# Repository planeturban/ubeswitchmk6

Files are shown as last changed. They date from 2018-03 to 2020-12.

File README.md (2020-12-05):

# Main functions
* Atari DIN13 to VGA
* 3.5mm A/V connector with volume control.
* Automatic detection of resolution.

# v1.4 update
Added a AG-pad (AG after the guy who requested it) cut trace and connect the other pad to feed h-sync to PB2 instead of v-sync. Updates to firmware is needed.

Please be aware that the PCB is **unrouted** since different PCB houses has different tolerances and it **might** mess up the end product. 

# Manual
Plug device into your Atari.

Turn your Atari on.

Press .25-1.999[...] seconds: Switch mode.

Press +2 seconds: store current mode as default at cold boot.

# Assembly tips
For least amount of wobbliness:
1. Backside SMD stuff (TS5V330, ATtiny85 and 78l05). 
2. Flip board over, solder all SMD.
3. DIN13
4. Lastly solder volume pot and VGA. Flipping of board is optional if you're a good at soldering.

# BOM
Part|Value|Device|Package|Description|MF|MPN|OC_FARNELL|OC_NEWARK|PACKAGE|PROD_ID|SUPPLIER|
--|--|----|----|---|--|---|-|-|-|-|-|
ATARIOUT|DIN13T|DIN13T|DIN13|||||||||
IC2|78L05F|78L05F|SOT89|POSITOIV-VOLTAGE REGULATORS||||||||
JP1||PINHD-1X2|1X02|PIN HEADER||||||||
S2||K2-1823SA||||||||||
TM1-3|100R|TRIMPOTTC33X|TC33X|SMT trimmer potentiometer part number TC33X||||||||
TS5V330||V330|SOIC16N|||||||||
U$1||PJ-320D||Audio jack - 3.5mm TRRS variety - two rings.||||||CONN-10676||
U$2|DB-1001N|DB-1001N|THUMB_POT|Multicomp||||||||
U1|ATTINY85-20SU|ATTINY85-20SU|SOIC127P798X216-8N|8-bit Microcontroller with In-System Programmable Flash||ATTINY85-20SU|1455164|58M3797|SOIC-8||Atmel|
X1||F15HDVS|HDF15V|SUB-D|||unknown|unknown||||

# Troubleshooting
 Symptom        | Solution|
| ------------- |:------|
|Constant switching|Check ATtiny soldering, probably rebooting. +5V and GND are possible offenders.|
|Dark picture.|Check soldering on multiplexer, pin 8 and 16 (GND and VCC).|
|Physical switch not working, software switching works.| Check soldering at ATtiny PB4 and soldering at the tactile switch itself.|
|Niether software or hardware switching works.| Check soldering ATtiny PB3 and multiplexer pin 1.|
|Niether software or hardware switching works, boots in low res.| Did you remember to program your ATtiny?|
|Software switch not working|Check soldering on ATtiny PB2 and V-sync on DIN|
|Hardware switch slow.|Did you set fuses ("Burn bootloader" in Arduino IDE) before programming ATtiny? Processor is probably running in 1MHz.|
|Won't hold saved state, switches to hires after cold boot.|Try upping bootWait, probably some timing issues at boot. A recap of PSU might be in place as well.|

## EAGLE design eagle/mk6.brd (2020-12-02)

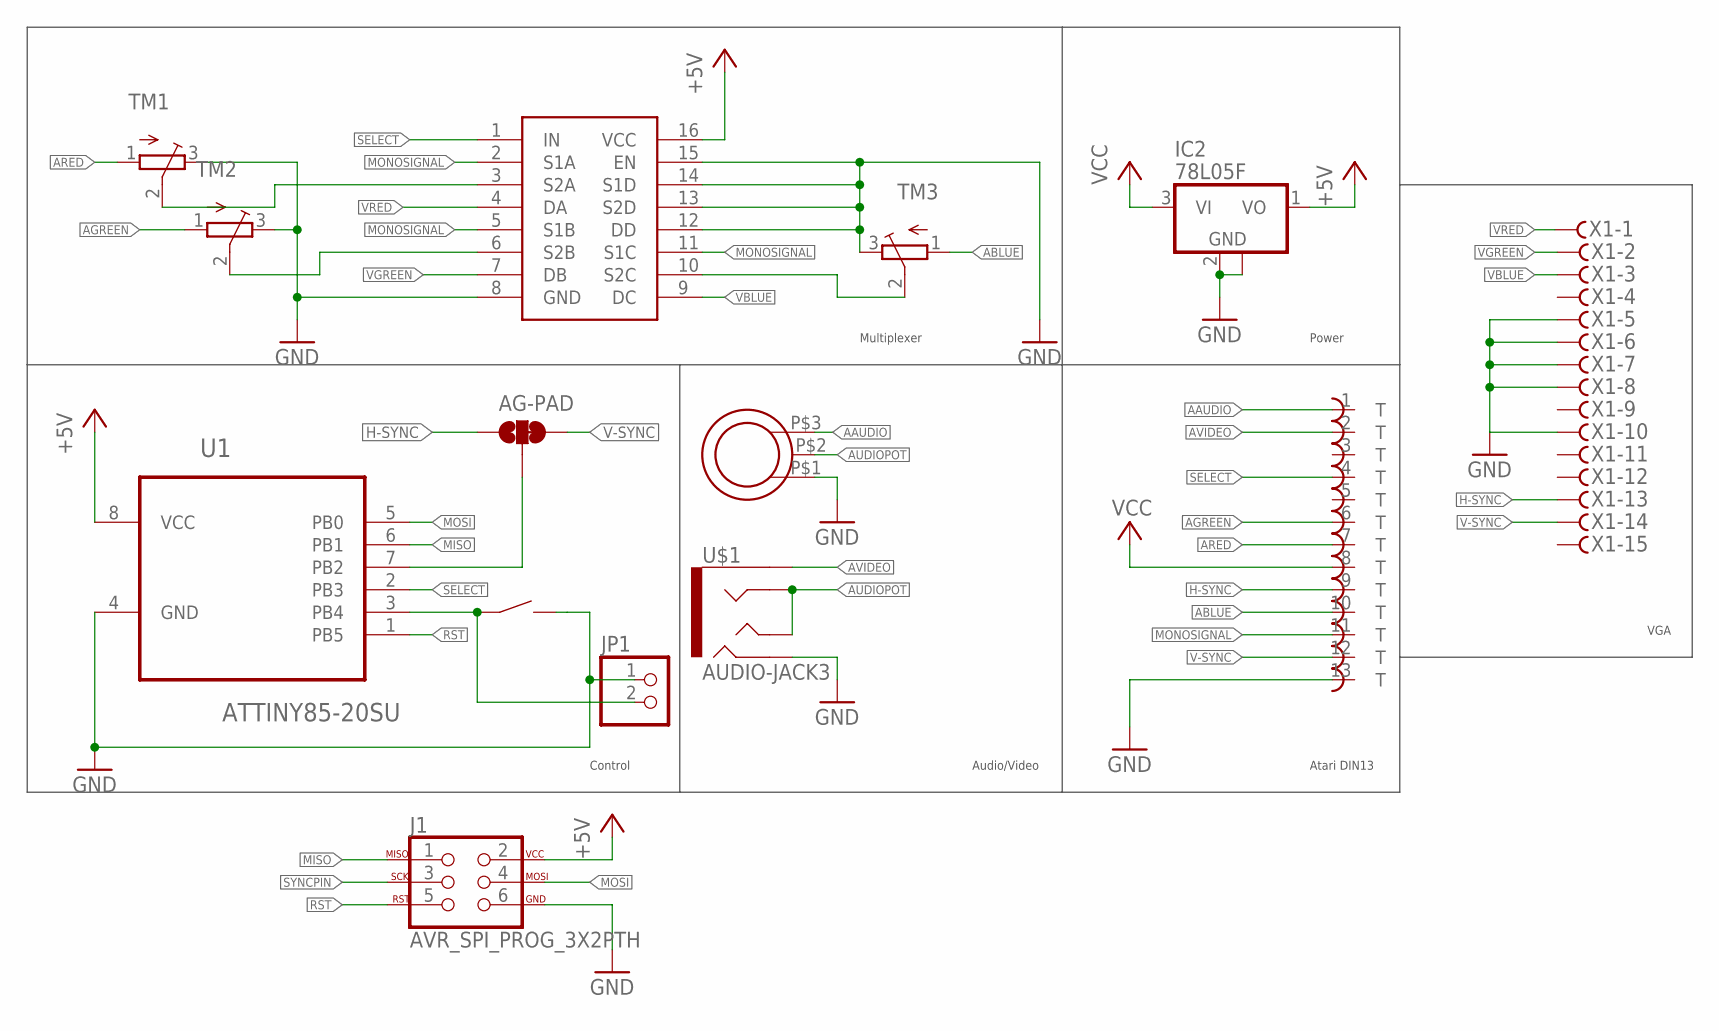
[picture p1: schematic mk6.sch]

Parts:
AG-PAD: JUMPER-SMT_3_1-NC_TRACE_SILK; SMT-JUMPER_3_1-NC_TRACE_SILK
ATARIOUT: DIN13T; ADADS
IC2: 78L05F; SOT89
J1: AVR_SPI_PROG_3X2PTH; 2X3
JP1: PINHD-1X2; 1X02
S2: K2-1823SA
TM1, TM2, TM3: TRIMPOTTC33X; TC33X
TS5V330: V330; SOIC16N
U1: ATTINY85-20SU; SOIC127P798X216-8N
U$1: AUDIO-JACK3; AUDIO-JACK-TRRS-SMD
U$2: DB-1001N; THUMB_POT
X1: F15HDVS; HDF15V

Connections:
+5V: IC2.1 (VO), J1.2, TS5V330.16 (VCC), U1.8 (VCC)
AAUDIO: ATARIOUT.1, U$2.P$3 (3)
ABLUE: ATARIOUT.10, TM3.1 (A)
AGREEN: ATARIOUT.6, TM2.1 (A)
ARED: ATARIOUT.7, TM1.1 (A)
AUDIOPOT: U$1.RING1, U$1.TIP, U$2.P$2 (2)
AVIDEO: ATARIOUT.2, U$1.EARTH
GND: ATARIOUT.13, IC2.2 (GND), IC2.2@1 (GND), J1.6, JP1.1, S2.P$2 (2), TM1.3 (E), TM2.3 (E), TM3.3 (E), TS5V330.8 (GND), TS5V330.12 (DD), TS5V330.13 (S2D), TS5V330.14 (S1D), TS5V330.15 (EN), U1.4 (GND), U$1.RING2, U$2.P$1 (1), X1.5, X1.6, X1.7, X1.8, X1.10
H-SYNC: AG-PAD.1, ATARIOUT.9, X1.13
MISO: J1.1, U1.6 (PB1)
MONOSIGNAL: ATARIOUT.11, TS5V330.2 (S1A), TS5V330.5 (S1B), TS5V330.11 (S1C)
MOSI: J1.4, U1.5 (PB0)
unnamed: JP1.2, S2.P$1 (1), U1.3 (PB4)
PBLUE: TM3.2 (S), TS5V330.10 (S2C)
PGREEN: TM2.2 (S), TS5V330.6 (S2B)
PRED: TM1.2 (S), TS5V330.3 (S2A)
RST: J1.5, U1.1 (PB5)
SELECT: ATARIOUT.4, TS5V330.1 (IN), U1.2 (PB3)
SYNCPIN: AG-PAD.2, J1.3, U1.7 (PB2)
V-SYNC: AG-PAD.3, ATARIOUT.12, X1.14
VBLUE: TS5V330.9 (DC), X1.3
VCC: ATARIOUT.8, IC2.3 (VI)
VGREEN: TS5V330.7 (DB), X1.2
VRED: TS5V330.4 (DA), X1.1

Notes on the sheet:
Audio/Video
Atari DIN13
Power
VGA
Multiplexer
Control

Board: 2 copper layers, 14 parts (6 on the bottom side), 24 nets, no tracks yet.

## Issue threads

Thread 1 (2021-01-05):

License is missing.

planeturban, 2021-01-05:
Add the following:

License:
Free (as in beer) for personal use. Commercial use comes with a 2 euro per sold unit donation to a non-profit organization
such as the Red Cross or Doctors without borders. Selling a maximum of four boards is considered personal use.

However, the name ubeswitch can not be used if the design is altered from checked in versions on GitHub without the explicit
permission from the author (Urban Jonsson/Planeturban/ube).

planeturban, 2021-01-05:
Added license.

Closed 2021-01-05.

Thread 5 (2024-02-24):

Soft reset or hard reset

dippaolo, 2024-02-24:
I work in high resolution.
I do a soft reset or hard reset and the Atari boots in low resolution.
I turn the Atari off and on and I have high resolution again.

Why does Atari boot in low resolution? Attiny has a high resolution saved.

planeturban, 2024-02-29:
It's by design, it's virtually impossible to distinguish a hot reboot (reset) from a mode switch; so many things that differ between physical machines.

But I'll update the documentation with this. I've mentioned this on forums, not here. :)

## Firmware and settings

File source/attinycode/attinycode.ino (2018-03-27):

/*
   Compiled with MicroCore: 980 bytes. (Not working..)
   Compiled for Attiny85: 956 bytes.
                          5244 bytes with debug.
How to read this code:
1. Don't. It's ugly.
2. When "pin" is referred in code (or text) it's the Atari side of things. The ATtiny's pins are always referred to as PBX. 

*/


//#define LEGACY // Uncomment this if your device does not have a ISP header.
//#define ALT_DETECT





//#define DEBUG


// Timings.
#define switchTime 250000
#define saveTime 2000000
#define bootWait 4000 // Wait for computer to stabilize, 3-4s seems ok.





#include <EEPROM.h>




#if defined(DEBUG) && !defined(LEGACY)
#include <SoftwareSerial.h>
SoftwareSerial mySerial(PB0, PB1); // RX, TX
#endif



#ifdef LEGACY
#define buttonPin PB0       // Connected to switch
#define selectPin PB1     // TS5V330 pin 1
#define pulsePin PB2       // VSync
#else
#define pulsePin PB2       // VSync
#define selectPin PB3     // TS5V330 pin 1
#define buttonPin PB4       // Connected to switch
#endif



unsigned long buttonPressedTime;
int pulseThreshold = 15000;

byte state;
byte lastState;
byte tosState;

#ifdef DEBUG
bool done = false;
String buff;
char data;
int i = 0;
#endif

unsigned long pulse = 0;


void setup() {
// IDEA: check if a jumper is placed on the ISP header to enter some kind of other operations mode. 


#if defined (DEBUG) && !defined(LEGACY)
  mySerial.begin(9600);
  mySerial.println("Boot");
#endif

  PORTB |= bit(buttonPin); // Input pullup.

  state = EEPROM.read(0);
// Instead of sending +5V to the Atari, let the pullup on pin4 handle the high part.
  bitWrite(DDRB, selectPin, state); 


#if defined (DEBUG) && !defined(LEGACY)
  mySerial.print("Waiting for ");
  mySerial.print(bootWait);
  mySerial.println(" milliseconds.");
#endif
  _delay_ms(bootWait);
  lastState = state;
#if defined (DEBUG) && !defined(LEGACY)
  if ( ! bitRead(PINB, buttonPin) )
    mySerial.println("Button held, prompt...");

  mySerial.print("> ");

/*
// Really need to fix this part.
  while ( ! done ) {
    if ( mySerial.available() > 0 ) {
      data = mySerial.read();
      mySerial.print(data);
      if ( int(data) != 10 ) {
        buff[i] = data;
        i++;
      } else {
        if ( buff[0] == "q" ) {
          done = true;
        } else if ( buff[0] == "h" ) {
          printHelp();
          clearBuff();
        } else if ( buff[0] == "b" ) {
          PORTB ^= bit(selectPin);
          clearBuff();
        } else if ( buff[0] == "s" ) {
          if ( buff[2] == " " )
            buff = buff.substring(2);
          else
            buff = buff.substring(1);
          int v = buff.toInt();
          clearBuff();
        } else {

          mySerial.println("Error in command.");
        }
      }
    }

  }
*/

    while ( ! bitRead(PINB, buttonPin) ); // Wait for button to be released.


  mySerial.println("Loop.");
#endif



}




#ifdef DEBUG
void clearBuff() {
  buff = "";
  i = 0;
  mySerial.print("> ");
}



void printHelp() {
  mySerial.println("Help");
  mySerial.println("-----------");
  mySerial.println("b       - Simulate button press.");
  mySerial.println("p       - Print information.");
  mySerial.println("q       - Quit prompt.");
  mySerial.println("s <num> - Set pulse threashold.");

}
#endif

void loop() {

  /*
     Detection..
  */
  pulse = 0;
#ifdef ALT_DETECT
  while ( pulse < 10000 ) // 10000 since sometimes you'd get 14 from getPulse();
    pulse = getPulse();
#else

  while ( ! pulse )
    pulse = pulseIn(pulsePin, HIGH, 1000000L);
#endif


  state = pulse < pulseThreshold;



  if ( state != lastState ) {
#if defined (DEBUG) && !defined(LEGACY)
    mySerial.println("State change");
    mySerial.print("New state: ");
    mySerial.println(state);
    mySerial.print("Pulse: ");
    mySerial.println(pulse);
#endif
    bitWrite(DDRB, selectPin, state);

  }
  lastState = state;

  /*
       Button, save and switch.
  */

  if ( !bitRead(PINB, buttonPin) ) {
    buttonPressedTime = micros();
    while ( ! bitRead(PINB, buttonPin)); // Ugly debounce
    if ( micros() > saveTime  + buttonPressedTime ) {
#if defined (DEBUG) && !defined(LEGACY)
      mySerial.println("Save");
      mySerial.print("Value: ");
      mySerial.println(state);
#endif
      EEPROM.write(0, state);
    } else if ( micros() > buttonPressedTime + switchTime ) {
#if defined (DEBUG) && !defined(LEGACY)
      mySerial.println("Switch");
#endif
      DDRB ^= bit(selectPin);

      _delay_ms(1000); // Wait for computer to reboot and get its shit togheter.
    }
  }
}

unsigned long getPulse() {
  pulse = bitRead(PINB, pulsePin);
  while ( bitRead(PINB, pulsePin) == pulse);
  unsigned long pstart = micros();
  while ( bitRead(PINB, pulsePin) != pulse);
  return ( micros() - pstart);
}

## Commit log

2018-03-27 Spring cleaning of code.
2020-01-03 v1.4. Added AG-pad, different button than 1.3b
    [mk6.brd, mk6.sch]
2020-01-03 Update BOM
2020-12-02 Removed routing since PCB houses differ..
    [mk6.brd]

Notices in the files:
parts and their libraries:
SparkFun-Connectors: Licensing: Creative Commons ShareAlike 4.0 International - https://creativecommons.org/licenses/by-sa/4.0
